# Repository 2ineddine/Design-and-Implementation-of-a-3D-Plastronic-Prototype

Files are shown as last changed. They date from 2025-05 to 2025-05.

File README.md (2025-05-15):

# 3D Plastronic Prototype with Arduino Control

## Project Overview
This project focuses on the design and implementation of an interactive electronic prototype that combines 3D plastronics with capacitive touch sensing. It consists of two functional 3D-printed plastic shells:

- A car shell equipped with programmable RGB LEDs
- A remote control shell featuring capacitive touch buttons using the MPR121 sensor

Both shells interface with an Arduino, enabling dynamic lighting effects triggered by user interactions through the touch interface.

## Objectives

- Design the electronic schematic and PCB layout using KiCad
- Integrate capacitive touch sensing via the MPR121 component
- Control RGB lighting effects using SK6812 addressable LEDs
- Manufacture two interactive shells using 3D printing: one for the car, one for the controller
- Demonstrate full system interaction through Arduino-based logic

## Components Used

| Component | Description |
|---|---|
| MPR121 | Capacitive touch sensor (I2C) |
| SK6812 RGB LEDs | Individually addressable LEDs |
| Resistors | 0805 and 1206 packages |
| Capacitors | 0805 decoupling capacitors |
| Arduino | Microcontroller (e.g., UNO or Nano)  |
| 3D-printed shells | Car and remote control enclosures |

## Tools and Software

- **KiCad**: For schematic capture and PCB layout
- **Arduino IDE**: For programming and uploading firmware
- **3D design software**: e.g., OpenSCAD or Fusion 360 for shell modeling
- **3D printer**: For producing the physical enclosures

## Project Structure

```
/ProjectFolder
├── code/                    # Arduino sketches for controlling LEDs and input logic
├── the_car_shell_model/    # STEP file of the car shell
├── file_of_prototypes/     # 3D models of the electronic boards and routing
└── detailed_report/        # Complete technical report in PDF format
```

## Example Features

- Touch input on the remote triggers LED animations on the car shell
- Multiple lighting modes: blink, fade, rainbow
- Modular and adaptable Arduino code

## References

- MPR121 Datasheet – Adafruit Guide  
- KiCad Documentation – https://docs.kicad.org  
- SK6812 RGB LED Datasheet

## Author

- Project by: 2ineddine  
- Date: May 2024  
- Academic Level: Bachelor's in Electronics and Embedded Systems

## License

This project is intended for educational and demonstration purposes only.  
Feel free to reuse and adapt with proper credit.

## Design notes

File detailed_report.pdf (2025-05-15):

# Design and Implementation of a 3D Plastronic Prototype

### 2ineddine

### May 2024

Abstract

In a world where electronics and materials science increasingly converge, this project explores the prototyping of a smart system integrating 3D plastronics and embedded electronics. The goal is to design and fabricate two functional shells—a vehicle and its remote controller—featuring capacitive touch interfaces and RGB lighting controlled by an Arduino. Using KiCad for circuit design and the MPR121 sensor for touch detection, we implemented a fully interactive, programmable prototype. This report details the engineering process, from schematic design to PCB realization and programming, highlighting the challenges and potential of integrating mechanical, electrical, and software components into a cohesive plastronic system.

## I PROJECT CONTEXT, PROBLEM AND OBJECTIVES

The goal of this project is to develop a functional prototype of a car using 3D plastronics technology. We are competing with two other teams and in the end, only one will remain. The challenges we face include:

- Creating an innovative and original product
- Exploring scientific and technical complexity in design
- Trying to make as much progress as possible

## II INTRODUCTION

At the intersection of plastics and electronics, plastronics represents a powerful lever of innovation for various industrial sectors. It paves the way for new advances in connected devices and embedded electronics, driving fields such as autonomous vehicles and connected health toward new horizons. This emerging field requires specialized technical skills, combining multiple disciplines such as electronics, materials science, and chemistry, and offers new career opportunities [4].
Also known as Molded Interconnect Device (MID), it is a rapidly growing field that merges plastics processing and electronics. Its aim is to integrate electrical and mechanical functions directly onto 3D plastic parts. Several plastronics manufacturing methods exist, depending on criteria such as technology cost estimates, performance range, associated connectors, and target applications, etc. [1] [6].
Two-shot molding (called 2K-molding in English) is a method that involves using two different materials in the injection process. This enables the creation of parts with specific characteristics by combining the advantages of each material. For example, one material may provide necessary structural strength, while the other offers electrical or thermal conductivity. While it requires a high initial investment, it becomes more cost-effective for large-scale production. One of its main advantages is the excellent freedom it offers for 3D shapes. This method is widely used in various industries to produce complex and functional components efficiently and precisely.
Laser ablation (called Laser Subtractive Structuring / LSS in English) involves initially molding the plastic substrate, followed by depositing a conductive metallic layer over the entire part. A laser is then used to remove the unwanted metal areas, leaving only the electronic circuit on the part. Finally, the thickness of the metal tracks is adjusted via electroplating. This method has several advantages, such as not requiring additives in the substrate material and offering high-resolution conductive paths. It is used in various fields, from low to high precision applications. Overmolded Structural Electronics (called IME – In Mold Electronics in English), derived from printed electronics, involves creating the electronic part using inks printed on thin plastic films. These films are then shaped and cut to fit the geometry of the molded product’s surfaces. Once the film is formed, it is placed in the injection molding tool and overmolded onto the plastic part. Its advantages include enhanced aesthetics, efficient and fast production, and the ability to use standard screen-printing machines for electronic printing, allowing component placement. Target applications include automotive, photovoltaics, and sensors [5].
This last method, as described, will be partially explored in the scope of this project. The equipment used and all subsequent steps were carried out in the AM-PER laboratory.
As third-year students in electronics, electrical energy, and automation, this initiative represents a valuable opportunity to apply our theoretical knowledge while developing practical skills in the design and fabrication of electronic prototypes. That’s why our team is excited about this challenge.

## III PROJECT PRESENTATION

As part of our project, we used the Overmolded Structural Electronics (OSE) method, which can be summarized in 6 steps described in Figure 1, to complete the mold of our project or any given mold.

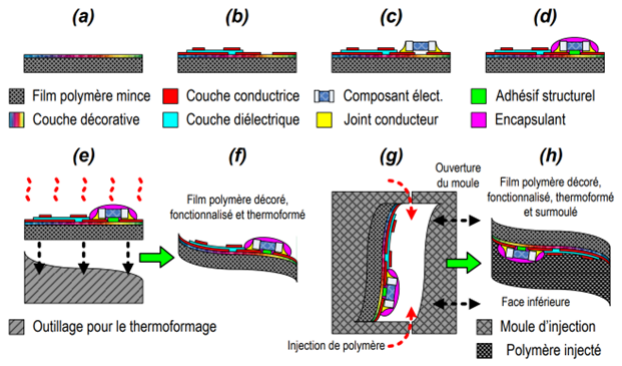
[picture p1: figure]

Figure 1: Manufacturing steps of a typical OSE plastronic process – (a) printing a decorative layer on a thin transparent polymer film; (b) successive printing of conductive and dielectric layers; (c) placing and assembling SMD electronic components on the conductive network; (d) structural bonding and/or encapsulation of components; (e) thermoforming; (f) trimming the system; (g) overmolding by injection; (h) final functionalized part.

A thin transparent polymer film with a thickness of around 200 to 400 µm, typically polycarbonate (PC), is used as the base substrate.
On one side of the film, successive printings — mainly using inks — are carried out to: deposit a decorative layer for aesthetic appeal (Fig. 1a), and deposit conductive and dielectric layers to build the circuit’s conductive network (Fig. 1b). Typically, the number of conductive layers is limited to two. The printing is usually done via screen printing, which allows significant material deposition (a few µm/pass), with a resolution around 50–200 µm. Other techniques or combinations may be used: digital printing, offset, pad printing, etc. SMD components are then placed using conventional placement machines onto the 2D interconnect network (Fig. 1c). They are mounted on pads previously coated with conductive glue (screen printed or point-to-point deposited), suitable for the PC’s glass transition temperature (Tg 140°C). To strengthen their hold and minimize detachment or "wash-out" issues during later steps, the components can be structurally glued and/or encapsulated (glob-top) (Fig. 1d). This increases mechanical adhesion and reduces the risk of detachment during overmolding.
The entire film is then thermoformed in 3D over a master mold (thermoforming mold) shaped to match the final object. Once trimmed (Fig. 1f), a functional polymer "shell" is obtained. It is then placed into a mold and overmolded with thermoplastic polymer (Fig. 1g). For material compatibility, the injected material is typically of the same nature as the base film.
The final result is a 3D printed circuit sandwiched between two protective polymer layers.

In this example, it’s worth noting that the decorative layer is on the same side as the conductive network. Although it could be on the opposite side, placing it on the same face offers better protection from external damage, as it’s shielded by the thickness of the (typically transparent) film. Variants or combinations of processes can be applied at each step — for instance: placing components after thermoforming; with or without overmolding using injection or casting (e.g., resins), etc.
The reference polymer (substrate + overmolding) is polycarbonate (PC), which offers good technical compromises. Other materials are also possible and/or being studied (Polypropylene – PP; Polylactic Acid – PLA; etc.).
The OSE process is an industrial method experiencing rapid growth. Its main advantages include:
- Production of both technical and aesthetic parts;
- A technology derived from printed electronics, using standardized 2D tools (printing and component placement) already mastered by the electronics industry;
- A technology using well-known plastic transformation techniques (thermoforming and overmolding);
- Functionalization of large flexible substrates without initial 3D shape complexity;
- Possibility of multiple conductive layers, though limited to one side of the film.

Some limitations include:

- Geometrical complexity of 3D parts is limited by thermoforming capacity (low aspect ratios and voluptuous surfaces);
- Use of conductive inks and glues with higher resistivity, and mechanical constraints during forming (stretching) and injection (wash-out);
- The Tg of commonly used polymers makes soldering difficult and limits use in high-power electronic applications;
- Difficult repair or intervention in case of system failure (due to overmolding);
- Low versatility with high tooling costs if design changes occur [3].

In our project, we were constrained to a shell mold. This shell will be used twice: once for a model resembling a car (Figure 2), and once for a controller described in detail in the project specifications.

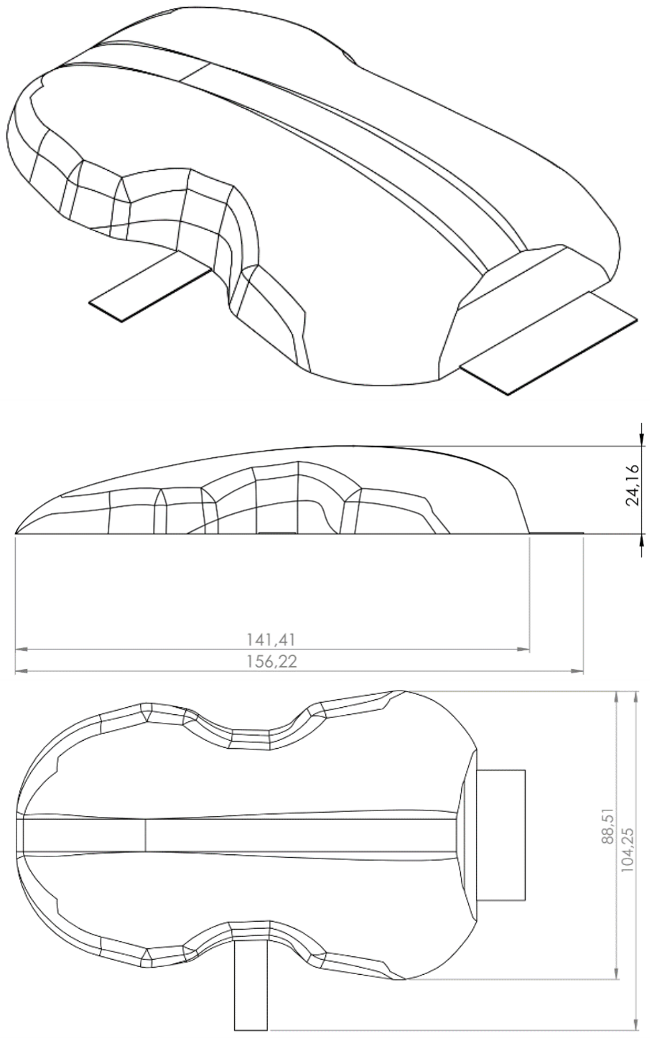
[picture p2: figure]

Figure 2: Actual dimensions of the car shell and controller

In our project, we used two similar shells to implement lighting functions on the "car" shell (from now on, we’ll refer to one as the car and the other as the controller), with the controller controlling the car shell. The circuits of both shells were entirely designed using the KiCad software. KiCad is a multi-platform tool that uses the open-source wxWidgets library. It allows all steps necessary for PCB design: schematic capture, footprint assignment, layout routing, and Gerber export [2].

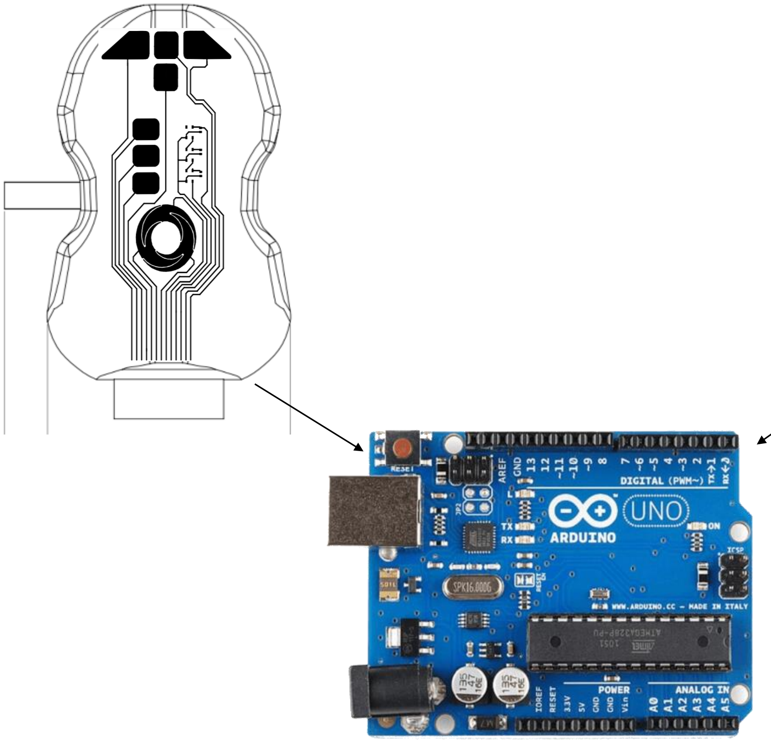
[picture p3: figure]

Figure 3: Complete demonstration of the project

## IV COMPONENTS USED

Figure 4 shows all the electronic components used to complete this project, excluding the routing ink.
Each LED must be accompanied by a capacitor to handle micro-outages or voltage drops, as they act as small energy sources located near the load to help stabilize voltage during rapid changes in energy demand.

Each path coming from an Arduino pin must include a resistor (0805 package) to limit strong current flow.

Bridge resistors (1206 package) of 0 Ω are used in printed circuit boards to resolve routing conflicts, especially when there are space constraints. These help bypass obstacles without redesigning the PCB and help avoid short circuits.

Capacitive touch sensors are used to control a device. The principle is based on the fact that our finger is a conductive object that alters the electrical capacitance when it approaches or touches the sensor electrode.

Initially, the sensor electrode and ground form a small capacitor with a baseline capacitance. When touched, the finger and electrode form a new capacitor in parallel with the original, increasing total capacitance. The change is measured and converted into digital values for processing by a microcontroller. In our case, we use the MPR121 (detailed in the programming section).

(a) | 1206 | resistor | —
1.3mm x 1.75mm
(b) | 0805 | resistor | —
1.2mm x 1.4mm

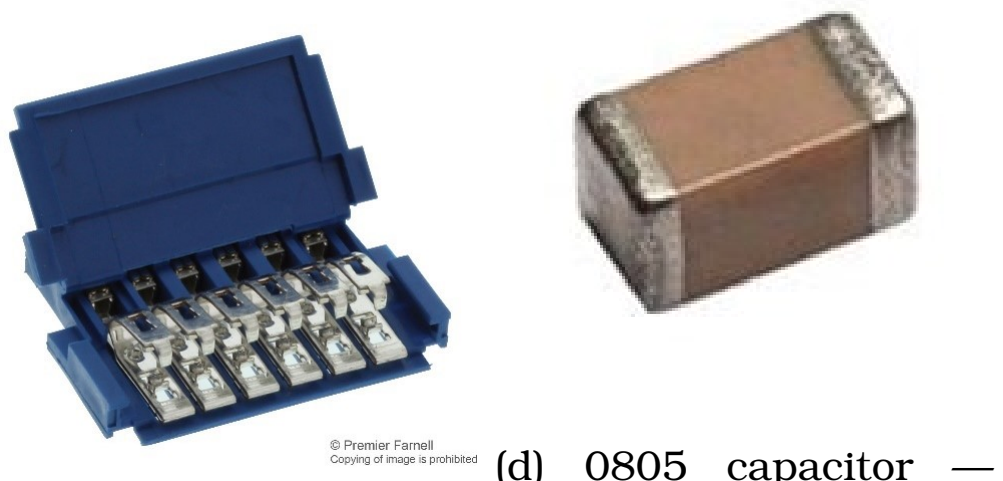
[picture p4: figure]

(c) Clincher
(d) 0805 capacitor —
1.18mm x 1.45mm
(e) RGB LEDs SK6812 —
5mm x 5mm

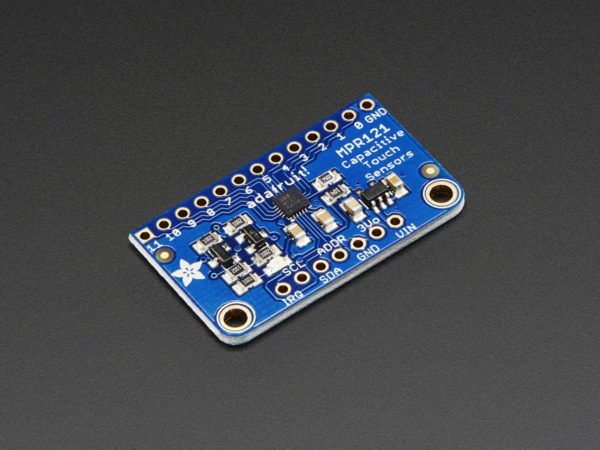
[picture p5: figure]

(f) | Touch | sensor
MPR121

Figure 4: Components used in this project

## V THE CAR SHELL

At this stage, we began implementing our ideas into a functional schematic and a PCB ready for fabrication using the KiCad software.

### V.1 Creating the Circuit Schematic

We start by creating a schematic file in KiCad. We select the components that will be part of the PCB circuit and define their connections. To generate the PCB file correctly, specific footprints must be assigned to each component, as previously explained. All these steps are illustrated in Figure 5.

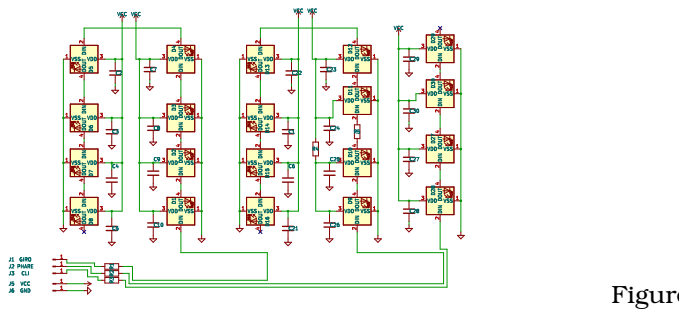
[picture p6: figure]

Figure 5: Schematic of the car shell’s LEDs

### V.2 PCB Design

We first select and place the components and other elements needed for the lighting functions.

After assigning footprints — a reminder: we used the SK6812 package for the 5mm x 5mm RGB LEDs, the 0805 package for capacitors and resistors, and 1206 package 0Ω bridge resistors. Since there were no constraints on external connectors, we used D-type pin connectors (D0.7mm, L6.5mm, W1.8mm FlatFork) in the circuit, along with a routing track width of about 0.6 mm, as shown in Figure 6.

Routing is one of the most important steps in PCB design. It involves placing components and connectors and drawing the electrical traces between them. This step required special attention, especially to minimize interference.

Figure 6: PCB layout of the car shell’s LEDs

VI THE | REMOTE | CONTROL

## SHELL

The design of the remote control shell requires the use of capacitive touch buttons based on the MPR121 component shown in Figure 4. The MPR121 transmits information about the activated touch pads to the Arduino via the I2C interface in the form of digital data. Each touch pad is represented by a bit in specific registers of the MPR121. When a pad is pressed, the corresponding bit is set to 1; when the pad is released, the bit returns to 0. The Arduino reads these registers to determine which touch pads are active, receiving this information as binary values (bits) instead of analog voltages.

The register from which the Arduino retrieves the number of the pressed touch pad is called the touch status register, specifically registers TS1 and TS2. These registers contain bits indicating the status of all 12 touch inputs (each bit corresponds to a pad: 1 if pressed, 0 if not) .

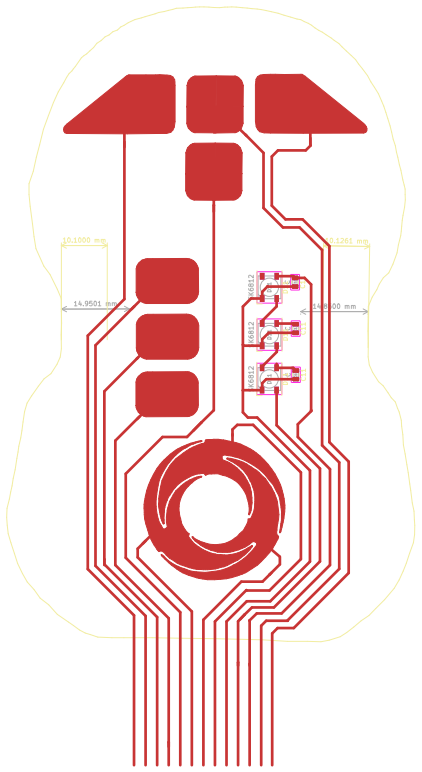
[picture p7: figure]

Figure 7: Schematic of the remote control shell

The lighting effects on the car shell as well as the behavior of the remote control shell can be programmed with various functionalities, since both are connected to the Arduino and their behavior depends primarily on the implemented code. One such example will be presented in the programming section.

## VII CONCLUSION

This project allowed us to explore the design and fabrication of a functional electronic prototype using 3D plastronics, from schematic creation to PCB realization and integration of capacitive touch control. By combining mechanical and electronic design, we implemented a complete system composed of two functional shells — a car and a remote control — communicating through an Arduino.
We successfully applied key concepts such as the use of the MPR121 touch sensor, I2C communication, RGB LED control, and PCB design with KiCad. This hands-on experience strengthened our understanding of circuit integration, component selection, and manufacturing constraints related to embedded

## References

[1] jade edu. Qu’est-ce que la plastronique ? 2021.
URL: https://jade- edu.org/quest- ce- que-
la-plastronique/ (https://jade-edu.org/quest-ce-que-la-plastronique/) (visited on 05/26/2024).
[2] Logiciel KiCad. URL: https : / / fr . wikipedia .
org/ (https://fr.wikipedia.org/) (visited on 05/26/2024).
[3] Philippe LOMBARD. “Etude et réalisation d’un projet dans le domaine de la platronique 3D”. In: (2024), 5 et 6.
[4] LYON1. Plastronique 3D. 2021. URL: https :
/ / www . universite - lyon . fr/ (https://www.universite-lyon.fr/) (visited on
05/26/2024).
[5] Olivier BARROSO et Pierre JOLY. Etude bibliographique / Etat de l’art Plastronique. NC. URL:
https://www.nae.fr/wp- content/uploads/ 2019/11/Etude-plastronique-Final.pdf (https://www.nae.fr/wp-content/uploads/2019/11/Etude-plastronique-Final.pdf) (vis-
ited on 05/26/2024).
[6] Lionel TENCHINE. Plastronique - Fonctionnalisation électronique des pièces plastiques. 2023.
URL: https : / / www . techniques - ingenieur . fr / base - documentaire / materiaux - th11 / applications - des - plastiques - 42141210 /
plastronique-am3610/ (https://www.techniques-ingenieur.fr/base-documentaire/materiaux-th11/applications-des-plastiques-42141210/plastronique-am3610/) (visited on 05/26/2024).

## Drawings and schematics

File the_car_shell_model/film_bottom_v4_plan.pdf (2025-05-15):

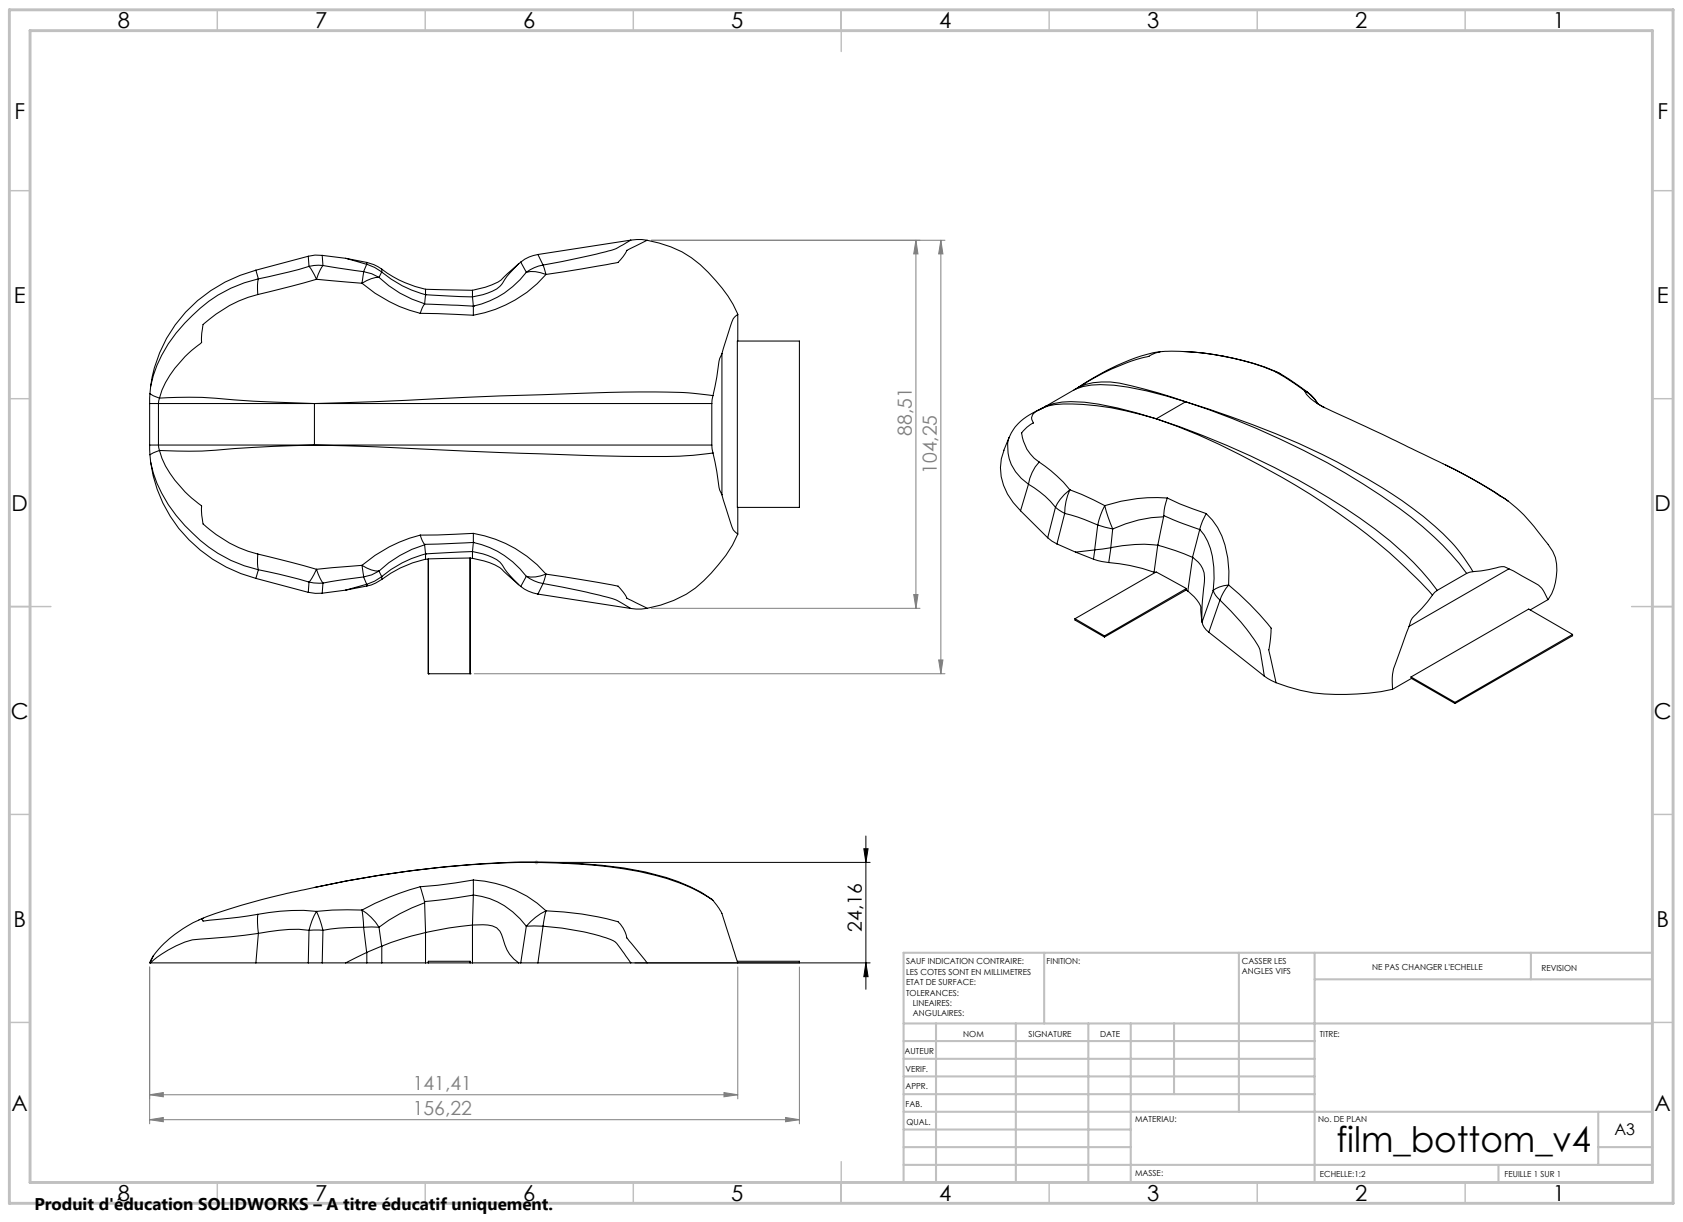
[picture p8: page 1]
FINITION:; CASSER LES; ANGLES VIFS; NE PAS CHANGER L'ECHELLE; REVISION; ECHELLE:1:2; FEUILLE 1 SUR 1

SAUF INDICATION CONTRAIRE:
LES COTES SONT EN MILLIMETRES
ETAT DE SURFACE:
TOLERANCES:
LINEAIRES:
ANGULAIRES:

NOM | SIGNATURE | DATE | TITRE:

AUTEUR
VERIF.
APPR.

No. DE PLAN
film_bottom_v4

Produit d'éducation SOLIDWORKS – A titre éducatif uniquement.

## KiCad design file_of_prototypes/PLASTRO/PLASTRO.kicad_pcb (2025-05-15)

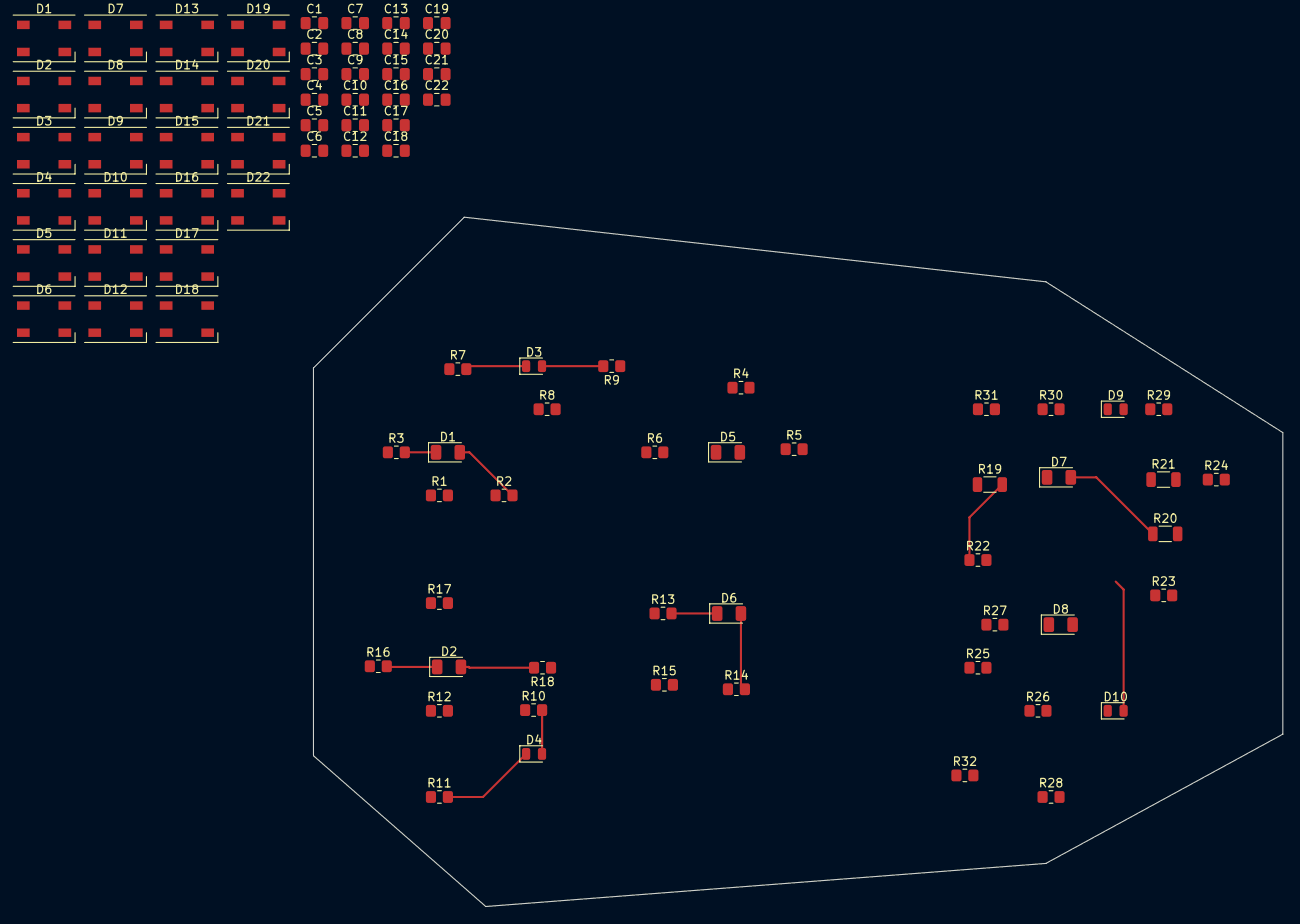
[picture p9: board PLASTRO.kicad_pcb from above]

Board: 2 copper layers, 114.3 x 81.3 mm, 86 parts (0 on the bottom side), 40 nets.

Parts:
C1, C2, C3, C4, C5, C6, C7, C8, C9, C10, C11, C12, C13, C14, C15, C16, C17, C18, C19, C20, C21, C22: C; C_0805_2012Metric_Pad1.18x1.45mm_HandSolder
D1, D2, D3, D4, D5#2, D6#2, D7#2, D8, D9#2, D10#2, D11, D12, D13, D14, D15, D16, D17, D18, D19, D20, D21, D22: SK6812; LED_SK6812_PLCC4_5.0x5.0mm_P3.2mm
D1#2, D2#2, D5, D6, D7, D8#2: LED_RGBK; LED_1206_3216Metric
D3#2, D4#2, D9, D10: LED_RGBK; LED_0805_2012Metric
R1, R2, R3, R4, R5, R6, R7, R8, R9, R10, R11, R12, R13, R14, R15, R16, R17, R18, R22, R23, R24, R25, R26, R27, R28, R29, R30, R31, R32: R_US; R_0805_2012Metric_Pad1.20x1.40mm_HandSolder
R19, R20, R21: R_US; R_1206_3216Metric

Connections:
unnamed: D1.4 (DOUT), D21.2 (DIN)
unnamed: D1#2.2 (GA), R2.2
unnamed: D1#2.1 (RA), R3.2
unnamed: D2.4 (DOUT), D22.2 (DIN)
unnamed: D2#2.2 (GA), R18.2
unnamed: D2#2.1 (RA), R16.2
unnamed: D3.4 (DOUT), D6#2.2 (DIN)
unnamed: D3#2.2 (GA), R9.2
unnamed: D3#2.1 (RA), R7.2
unnamed: D4.4 (DOUT), D7#2.2 (DIN)
unnamed: D4#2.2 (GA), R10.2
unnamed: D4#2.1 (RA), R11.2
unnamed: D5#2.2 (DIN), D7#2.4 (DOUT)
unnamed: D5.2 (GA), R5.2
unnamed: D5.1 (RA), R6.2
unnamed: D6#2.4 (DOUT), D8.2 (DIN)
unnamed: D6.2 (GA), R14.2
unnamed: D6.1 (RA), R13.2
unnamed: D7.2 (GA), R20.1
unnamed: D7.1 (RA), R21.1
unnamed: D8#2.2 (GA), R26.1
unnamed: D8#2.1 (RA), R27.1
unnamed: R28.1, R32.2
unnamed: D9.1 (RA), R30.2
unnamed: D9#2.2 (DIN), D10#2.4 (DOUT)
unnamed: D9.2 (GA), D10.2 (GA), R29.1
unnamed: D10.1 (RA), R30.1, R31.1
unnamed: D11.2 (DIN), D12.4 (DOUT)
unnamed: D11.4 (DOUT), D13.2 (DIN)
unnamed: D9#2.4 (DOUT), D12.2 (DIN)
unnamed: D13.4 (DOUT), D16.2 (DIN)
unnamed: D14.2 (DIN), D16.4 (DOUT)
unnamed: D14.4 (DOUT), D15.2 (DIN)
unnamed: D17.4 (DOUT), D20.2 (DIN)
unnamed: D18.4 (DOUT), D19.2 (DIN)
unnamed: R19.2, R22.1
unnamed: R20.2, R23.1
unnamed: R21.2, R24.1
VCC: C1.1, C2.1, C3.1, C4.1, C5.1, C6.1, C7.1, C8.1, C9.1, C10.1, C11.1, C12.1, C13.1, C14.1, C15.1, C16.1, C17.1, C18.1, C19.1, C20.1, C21.1, C22.1, D1.3 (VDD), D2.3 (VDD), D3.3 (VDD), D4.3 (VDD), D5#2.3 (VDD), D6#2.3 (VDD), D7#2.3 (VDD), D8.3 (VDD), D9#2.3 (VDD), D10#2.3 (VDD), D11.3 (VDD), D12.3 (VDD), D13.3 (VDD), D14.3 (VDD), D15.3 (VDD), D16.3 (VDD), D17.3 (VDD), D18.3 (VDD), D19.3 (VDD), D20.3 (VDD), D21.3 (VDD), D22.3 (VDD)
gnd: C1.2, C2.2, C3.2, C4.2, C5.2, C6.2, C7.2, C8.2, C9.2, C10.2, C11.2, C12.2, C13.2, C14.2, C15.2, C16.2, C17.2, C18.2, C19.2, C20.2, C21.2, C22.2, D1.1 (VSS), D2.1 (VSS), D3.1 (VSS), D4.1 (VSS), D5#2.1 (VSS), D6#2.1 (VSS), D7#2.1 (VSS), D8.1 (VSS), D9#2.1 (VSS), D10#2.1 (VSS), D11.1 (VSS), D12.1 (VSS), D13.1 (VSS), D14.1 (VSS), D15.1 (VSS), D16.1 (VSS), D17.1 (VSS), D18.1 (VSS), D19.1 (VSS), D20.1 (VSS), D21.1 (VSS), D22.1 (VSS)

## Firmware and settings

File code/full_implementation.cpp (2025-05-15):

/* ---------------------------------------------------------------------------
 *  Emergency-light controller for an Adafruit MPR121 touch-pad + NeoPixels
 *  --------------------------------------------------------------------------
 *  – Gyro beacon (8 pixels, PIN 2)
 *  – Turn signals  (4 pixels, PIN 0)
 *  – Head + tail   (8 pixels, PIN 4)
 *
 *  A short tap toggles each feature ON / OFF.
 *  A double-tap (< 500 ms) enters a “brightness / colour” setup loop that is
 *  confirmed with CTRL (electrode 5).
 *  ------------------------------------------------------------------------ */

#include <Wire.h>
#include <Adafruit_NeoPixel.h>
#include <Adafruit_MPR121.h>

#ifndef _BV
#  define _BV(bit)  (1U << (bit))
#endif

/* ---------------------------------------------------------------------------
 *  Pin-map & pixel counts
 * ------------------------------------------------------------------------ */
constexpr uint8_t  PIN_GYRO         = 2;   // Gyro beacon strip
constexpr uint8_t  PIN_TURN         = 0;   // Turn-signal strip
constexpr uint8_t  PIN_HEAD_TAIL    = 4;   // Head-/tail-light strip
constexpr uint8_t  POT_PIN          = 13;  // Analogue pot for brightness / colour

constexpr uint8_t  NUM_GYRO_PIXELS       = 8;
constexpr uint8_t  NUM_TURN_PIXELS       = 4;
constexpr uint8_t  NUM_HEADTAIL_PIXELS   = 8;

/* ---------------------------------------------------------------------------
 *  Timing (half-periods, in ms)
 * ------------------------------------------------------------------------ */
constexpr uint16_t HP_TURN  = 500;
constexpr uint16_t HP_GYRO  = 500;

/* ---------------------------------------------------------------------------
 *  Touch IDs (one bit per electrode)
 * ------------------------------------------------------------------------ */
constexpr uint16_t TK_GYRO          = _BV(0);
constexpr uint16_t TK_TURN_R        = _BV(1);
constexpr uint16_t TK_TURN_L        = _BV(2);
constexpr uint16_t TK_HEAD          = _BV(3);
constexpr uint16_t TK_TAIL          = _BV(4);
constexpr uint16_t TK_CTRL          = _BV(5);
constexpr uint16_t TK_SHOW          = _BV(6);

constexpr uint16_t TK_HAZARD        = TK_TURN_R | TK_TURN_L;
constexpr uint16_t TK_LOW_BEAM      = TK_HEAD    | TK_TAIL;
constexpr uint16_t TK_HEAD_COL      = TK_CTRL    | TK_HEAD;
constexpr uint16_t TK_TAIL_COL      = TK_CTRL    | TK_TAIL;

/* ---------------------------------------------------------------------------
 *  Objects
 * ------------------------------------------------------------------------ */
Adafruit_NeoPixel pxGyro (NUM_GYRO_PIXELS,     PIN_GYRO,      NEO_GRB + NEO_KHZ800);
Adafruit_NeoPixel pxTurn (NUM_TURN_PIXELS,     PIN_TURN,      NEO_GRB + NEO_KHZ800);
Adafruit_NeoPixel pxMain (NUM_HEADTAIL_PIXELS, PIN_HEAD_TAIL, NEO_GRB + NEO_KHZ800);

Adafruit_MPR121   cap;

/* ---------------------------------------------------------------------------
 *  State flags
 * ------------------------------------------------------------------------ */
bool gyroEnabled         = false;
bool turnR_Enabled       = false;
bool turnL_Enabled       = false;
bool hazardEnabled       = false;
bool headEnabled         = false;
bool tailEnabled         = false;
bool lowBeamEnabled      = false;

bool cfgGyroBrightness   = false;
bool cfgTurnBrightness   = false;
bool cfgMainBrightness   = false;
bool cfgColour           = false;

/* Runtime helpers */
unsigned long tLastGyro      = 0;
unsigned long tLastTurnR     = 0;
unsigned long tLastTurnL     = 0;
unsigned long tLastHazard    = 0;

/* Double-tap bookkeeping */
struct TapTimer {
  uint8_t       count  = 0;
  unsigned long first  = 0;
};
TapTimer tapGyro, tapTurnR, tapTurnL, tapMain;

/* ---------------------------------------------------------------------------
 *  User presets (will be updated from setup loops)
 * ------------------------------------------------------------------------ */
uint8_t  brGyroInit   = 100;                                // 0-255
uint8_t  brTurnInit   = 100;
uint8_t  brMainInit   = 100;

uint32_t colHeadInit  = pxMain.Color(230, 240, 255);        // bluish-white
uint32_t colTailInit  = pxMain.Color(255,   0,   0);        // red
uint32_t colTurnInit  = pxMain.Color(255, 165,   0);        // amber
uint32_t colGyroA     = pxMain.Color(255,   0,   0);        // red
uint32_t colGyroB     = pxMain.Color(  0,   0, 255);        // blue

/* Demo / show-mode colours */
const uint32_t colShowGyroA = pxMain.Color( 38, 196, 236);
const uint32_t colShowGyroB = pxMain.Color( 20, 148,  20);
const uint32_t colShowTurn  = pxMain.Color(187, 210, 225);
const uint32_t colShowMain  = pxMain.Color(255,   0, 127);

/* ---------------------------------------------------------------------------
 *  Forward declarations
 * ------------------------------------------------------------------------ */
void clearStrip(Adafruit_NeoPixel &strip);
void toggleGyro  (bool state, uint32_t c1, uint32_t c2);
void toggleTurnR (bool state, uint32_t c);
void toggleTurnL (bool state, uint32_t c);
void toggleHazard(bool state, uint32_t c);
void toggleHead  (bool state, uint32_t c);
void toggleTail  (bool state, uint32_t c);
void toggleLowBeam(bool state, uint32_t c);

uint8_t  potToBrightness(int raw);
uint32_t potToWhiteShade (int raw);
uint32_t potToRedShade   (int raw);
uint32_t potToAmberShade (int raw);

void waitRelease(uint8_t electrode);

/* ---------------------------------------------------------------------------
 *  SETUP
 * ------------------------------------------------------------------------ */
void setup()
{
  Serial.begin(9600);

  pxGyro.begin();
  pxTurn.begin();
  pxMain.begin();

  pxGyro.setBrightness(brGyroInit);
  pxTurn.setBrightness(brTurnInit);
  pxMain.setBrightness(brMainInit);

  clearStrip(pxGyro);
  clearStrip(pxTurn);
  clearStrip(pxMain);

  if (!cap.begin(0x5A))
  {
    Serial.println(F("MPR121 not found – check wiring!"));
    while (true) ;
  }
}

/* ---------------------------------------------------------------------------
 *  LOOP
 * ------------------------------------------------------------------------ */
void loop()
{
  uint16_t touchNow = cap.touched();
  if (touchNow) {
    Serial.print(F("Touch 0x"));
    Serial.print(touchNow, HEX);
    Serial.println(F(" detected"));
  }

  /* -----------------------------------------------------------------------
   *  GYRO BEACON  ──────────────────────────────────────────────────────────
   * -------------------------------------------------------------------- */
  handleTap(touchNow, TK_GYRO, tapGyro, cfgGyroBrightness, gyroEnabled,
            tLastGyro, HP_GYRO,
            [](){                 // on-toggle
              gyroEnabled = !gyroEnabled;
              tLastGyro   = millis() - HP_GYRO;   // sync phase
              if (gyroEnabled)
                toggleGyro(true, colGyroA, colGyroB);
              else
                clearStrip(pxGyro);
            },
            [](){                 // brightness-config loop
              cfgGyroBrightness = true;
              while (cfgGyroBrightness) {
                int raw  = analogRead(POT_PIN);
                uint8_t br = potToBrightness(raw);
                pxGyro.setBrightness(br);
                toggleGyro(true, colGyroA, colGyroB);

                if (cap.touched() == TK_CTRL) {
                  brGyroInit = br;
                  waitRelease(5);
                  cfgGyroBrightness = false;
                  gyroEnabled = false;
                  clearStrip(pxGyro);
                }
                if (cap.touched() == TK_GYRO) {
                  pxGyro.setBrightness(brGyroInit);
                  waitRelease(0);
                  cfgGyroBrightness = false;
                  gyroEnabled = false;
                  clearStrip(pxGyro);
                }
              }
            });

  /* Half-period blinking while gyro is active */
  if (gyroEnabled && millis() - tLastGyro >= HP_GYRO) {
    tLastGyro += HP_GYRO;
    static bool phase = false;
    phase = !phase;
    toggleGyro(phase, colGyroA, colGyroB);
  }

  /* Colour swap: CTRL + GYRO (white ↔ red for the first 4 pixels) */
  if (touchNow == TK_CTRL | TK_GYRO) {
    while (cap.touched() == (TK_CTRL | TK_GYRO)) delay(10);
    colGyroA = (colGyroA == pxGyro.Color(255,255,255)) ?
               pxGyro.Color(255,0,0) : pxGyro.Color(255,255,255);
  }

  /* -----------------------------------------------------------------------
   *  TURN SIGNALS  (RIGHT / LEFT / HAZARD)
   * -------------------------------------------------------------------- */
  handleTap(touchNow, TK_TURN_R, tapTurnR, cfgTurnBrightness, turnR_Enabled,
            tLastTurnR, HP_TURN,
            [](){                                  // toggle right
              turnR_Enabled = !turnR_Enabled;
              tLastTurnR    = millis() - HP_TURN;
              if (turnR_Enabled)  toggleTurnR(true, colTurnInit);
              else                clearStrip(pxTurn);
              turnL_Enabled   = false;
              hazardEnabled   = false;
            },
            [](){                                  // brightness setup
              cfgTurnBrightness = true;
              while (cfgTurnBrightness) {
                int raw  = analogRead(POT_PIN);
                uint8_t br = potToBrightness(raw);
                pxTurn.setBrightness(br);
                toggleHazard(true, colTurnInit);

                if (cap.touched() == TK_CTRL) {
                  brTurnInit = br;
                  waitRelease(5);
                  cfgTurnBrightness = false;
                  clearStrip(pxTurn);
                }
                if (cap.touched() & TK_HAZARD) {
                  pxTurn.setBrightness(brTurnInit);
                  waitRelease(1);  // either electrode 1 or 2 is fine
                  cfgTurnBrightness = false;
                  clearStrip(pxTurn);
                }
              }
            });

  /* Blink right */
  if (turnR_Enabled && millis() - tLastTurnR >= HP_TURN && !turnL_Enabled) {
    tLastTurnR += HP_TURN;
    static bool phaseR = false;
    phaseR = !phaseR;
    toggleTurnR(phaseR, colTurnInit);
  }

  /* ─────────────────────────────────────────────────────────────────---- */
  handleTap(touchNow, TK_TURN_L, tapTurnL, cfgTurnBrightness, turnL_Enabled,
            tLastTurnL, HP_TURN,
            [](){                                  // toggle left
              turnL_Enabled = !turnL_Enabled;
              tLastTurnL    = millis() - HP_TURN;
              if (turnL_Enabled)  toggleTurnL(true, colTurnInit);
              else                clearStrip(pxTurn);
              turnR_Enabled   = false;
              hazardEnabled   = false;
            },
            [](){});   // brightness config handled above – skip here

  /* Blink left */
  if (turnL_Enabled && millis() - tLastTurnL >= HP_TURN) {
    tLastTurnL += HP_TURN;
    static bool phaseL = false;
    phaseL = !phaseL;
    toggleTurnL(phaseL, colTurnInit);
  }

  /* ─────────────────────────────────────────────────────────────────---- */
  /* Hazard (both turn buttons together) */
  if (touchNow == TK_HAZARD) {
    hazardEnabled = !hazardEnabled;
    tLastHazard   = millis() - HP_TURN;
    if (hazardEnabled)  toggleHazard(true, colTurnInit);
    else                clearStrip(pxTurn);
    turnL_Enabled = turnR_Enabled = false;
    waitRelease(1);   // wait until both electrodes are clear
  }
  if (hazardEnabled && millis() - tLastHazard >= HP_TURN) {
    tLastHazard += HP_TURN;
    static bool phaseH = false;
    phaseH = !phaseH;
    toggleHazard(phaseH, colTurnInit);
  }

  /* -----------------------------------------------------------------------
   *  HEAD- / TAIL-LIGHTS
   * -------------------------------------------------------------------- */
  handleTap(touchNow, TK_HEAD, tapMain, cfgMainBrightness, headEnabled,
            /* timer not needed */ tLastGyro, HP_TURN,
            [](){                                   // toggle headlights
              lowBeamEnabled = false;
              headEnabled = !headEnabled;
              if (headEnabled) toggleHead(true,  colHeadInit);
              else             clearStrip(pxMain);
            },
            [](){                                   // brightness setup
              cfgMainBrightness = true;
              toggleHead(true, colHeadInit);
              toggleTail(true, colTailInit);
              while (cfgMainBrightness) {
                int raw  = analogRead(POT_PIN);
                uint8_t br = potToBrightness(raw);
                pxMain.setBrightness(br);

                if (cap.touched() == TK_CTRL) {
                  brMainInit = br;
                  waitRelease(5);
                  cfgMainBrightness = false;
                  clearStrip(pxMain);
                  headEnabled = tailEnabled = false;
                }
                if (cap.touched() == TK_HEAD) {
                  pxMain.setBrightness(brMainInit);
                  waitRelease(3);
                  cfgMainBrightness = false;
                  clearStrip(pxMain);
                  headEnabled = tailEnabled = false;
                }
              }
            });

  /* Tail lights (simple ON/OFF) */
  if (touchNow == TK_TAIL) {
    tailEnabled = !tailEnabled;
    toggleTail(tailEnabled, colTailInit);
    waitRelease(4);
  }

  /* Low beam (head + tail together) */
  if (touchNow == TK_LOW_BEAM) {
    lowBeamEnabled = !lowBeamEnabled;
    toggleLowBeam(lowBeamEnabled, colHeadInit);
    waitRelease(3);   // release both 3 & 4
  }

  /* -----------------------------------------------------------------------
   *  COLOUR CONFIGURATION LOOPS
   * -------------------------------------------------------------------- */
  if (touchNow == TK_HEAD_COL) {
    cfgColour = true;
    while (cfgColour) {
      int raw  = analogRead(POT_PIN);
      uint32_t c = potToWhiteShade(raw);
      toggleHead(true, c);

      if (cap.touched() == TK_CTRL) {
        colHeadInit = c;
        waitRelease(5);
        cfgColour = false;
        clearStrip(pxMain);
      }
      if (cap.touched() == TK_HEAD) {
        waitRelease(3);
        cfgColour = false;
        clearStrip(pxMain);
      }
    }
  }

  if (touchNow == TK_TAIL_COL) {
    cfgColour = true;
    while (cfgColour) {
      int raw  = analogRead(POT_PIN);
      uint32_t c = potToRedShade(raw);
      toggleTail(true, c);

      if (cap.touched() == TK_CTRL) {
        colTailInit = c;
        waitRelease(5);
        cfgColour = false;
        clearStrip(pxMain);
      }
      if (cap.touched() == TK_TAIL) {
        waitRelease(4);
        cfgColour = false;
        clearStrip(pxMain);
      }
    }
  }

  /* -----------------------------------------------------------------------
   *  DEMO “SHOW MODE”
   * -------------------------------------------------------------------- */
  if (touchNow == TK_SHOW) {
    waitRelease(6);                 // debouncing
    demoShowMode();
  }
}

/* ===========================================================================
 *  HELPER FUNCTIONS
 * ======================================================================== */
/* ---------------------------------------------------------------------------
 *  handleTap()
 *  ----------
 *  Generic double-tap detector + dispatcher.
 * ------------------------------------------------------------------------ */
template<typename ToggleFn, typename CfgFn>
void handleTap(uint16_t touchNow,
               uint16_t keyMask,
               TapTimer &tap,
               bool &cfgFlag,
               bool &featureFlag,
               unsigned long &tLast,
               uint16_t halfPeriod,
               ToggleFn onToggle,
               CfgFn    onConfig)
{
  /* flush stale taps (>1 s) */
  if (tap.count && millis() - tap.first > 1000) tap.count = 0;

  if (touchNow == keyMask) {            // electrode touched
    tap.count++;
    if (tap.count == 1) tap.first = millis();

    /* Double-tap → config loop */
    if (tap.count == 2 && millis() - tap.first < 500) {
      tap.count = 0;
      cfgFlag   = true;
      onConfig();
      return;
    }

    /* Single tap → ON / OFF */
    if (tap.count == 1) {
      onToggle();
    }
    waitRelease(__builtin_ctz(keyMask));   // wait for release of that electrode
  }

  /* Blinking handled outside */
}

/* ---------------------------------------------------------------------------
 *  Strip helpers
 * ------------------------------------------------------------------------ */
void clearStrip(Adafruit_NeoPixel &strip)
{
  for (uint16_t i = 0; i < strip.numPixels(); ++i)
    strip.setPixelColor(i, 0);
  strip.show();
}

void toggleGyro(bool phase, uint32_t c1, uint32_t c2)
{
  /* Two interleaved groups of four pixels */
  for (uint8_t i = 0; i < 8; ++i) {
    bool groupA = (i < 2) || (i > 5);
    pxGyro.setPixelColor(i, phase ^ groupA ? c1 : c2);
  }
  pxGyro.show();
}

void toggleTurnR(bool phase, uint32_t c)
{
  pxTurn.setPixelColor(2, phase ? c : 0);
  pxTurn.setPixelColor(3, phase ? c : 0);
  pxTurn.show();
}
void toggleTurnL(bool phase, uint32_t c)
{
  pxTurn.setPixelColor(0, phase ? c : 0);
  pxTurn.setPixelColor(1, phase ? c : 0);
  pxTurn.show();
}
void toggleHazard(bool phase, uint32_t c)
{
  for (uint8_t i = 0; i < NUM_TURN_PIXELS; ++i)
    pxTurn.setPixelColor(i, phase ? c : 0);
  pxTurn.show();
}

void toggleHead(bool on, uint32_t c)
{
  static const uint8_t idx[] = {0,2,3,4,5,7};
  for (uint8_t i : idx) pxMain.setPixelColor(i, on ? c : 0);
  pxMain.show();
}
void toggleTail(bool on, uint32_t c)
{
  pxMain.setPixelColor(1, on ? c : 0);
  pxMain.setPixelColor(6, on ? c : 0);
  pxMain.show();
}
void toggleLowBeam(bool on, uint32_t c)
{
  static const uint8_t idx[] = {0,2,5,7};
  for (uint8_t i : idx) pxMain.setPixelColor(i, on ? c : 0);
  pxMain.show();
}

/* ---------------------------------------------------------------------------
 *  Analogue helpers
 * ------------------------------------------------------------------------ */
uint8_t potToBrightness(int raw)
{
  raw = constrain(raw, 0, 4095);
  return map(raw, 0, 4095, 0, 255);            // full 8-bit range
}
uint32_t potToWhiteShade(int raw)
{
  raw = constrain(raw, 0, 4095);
  byte pos = map(raw, 0, 4095, 0, 120);
  return pxMain.Color(230 - pos, 240 - pos, 255 - pos / 3);
}
uint32_t potToRedShade(int raw)
{
  raw = constrain(raw, 0, 4095);
  byte pos = map(raw, 0, 4095, 0, 100);
  return pxMain.Color(255 - pos / 3, pos / 8, pos);
}
uint32_t potToAmberShade(int raw)
{
  raw = constrain(raw, 0, 4095);
  byte pos = map(raw, 0, 4095, 0, 120);
  return pxMain.Color(255 - pos / 5, 165 - pos / 2, 0);
}

/* Wait until a given electrode is released */
void waitRelease(uint8_t electrode)
{
  while (cap.touched() & _BV(electrode)) delay(10);
}

/* ---------------------------------------------------------------------------
 *  SHOW MODE – fancy demo lights (press electrode 6 to start)
 * ------------------------------------------------------------------------ */
void demoShowMode()
{
  /* Reset strips and brightness */
  pxGyro.setBrightness(brGyroInit);
  pxTurn.setBrightness(brTurnInit);
  pxMain.setBrightness(brMainInit);
  clearStrip(pxGyro);
  clearStrip(pxTurn);
  clearStrip(pxMain);

  /* Sequencer */
  bool running = true;
  uint32_t tStart = millis();
  uint8_t  order  = 0;     // 0-3 for the four centre pixels
  while (running)
  {
    /* --- Gyro flash ---------------------------------------------------- */
    bool phase = ((millis() - tStart) / 500) & 1;
    toggleGyro(phase, colShowGyroA, colShowGyroB);

    /* --- Turn & head chaser ------------------------------------------- */
    toggleHazard(phase, colShowTurn);

    /* middle pixel “bouncing” */
    static const uint8_t centre[] = {1,2,5,6};
    if (((millis() - tStart) / 500) % 2 == 0) {   // every second period
      pxMain.setPixelColor(centre[order], colShowMain);
      pxMain.setPixelColor(centre[(order + 3) % 4], 0);
      pxMain.show();
      order = (order + 1) & 3;
    }

    if (cap.touched() == TK_SHOW) {
      waitRelease(6);
      running = false;
    }
    delay(20);
  }
  /* Clean-up */
  clearStrip(pxGyro);
  clearStrip(pxTurn);
  clearStrip(pxMain);
}
